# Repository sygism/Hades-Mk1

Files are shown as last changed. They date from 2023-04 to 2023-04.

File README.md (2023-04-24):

# Hades-Mk1

Hades-Mk1 is a collection of electronics designs for a quadcopter. This repository includes the designs for an NXP MCU based flight controller and compatible ESC (electronic speed controller) board for BLDC motors. More in-depth descriptions of the designs are included under the corresponding folders.

## Authors

  - **Markus Erik Sügis** - 
    [sygism](https://github.com/sygism)

## License

This project is not licensed and is free to be used in any way.

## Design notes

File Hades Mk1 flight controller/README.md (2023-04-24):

# Hades Mk1 FC board

The Hades Mk1 FCU board is designed for quadcopter control.

## Microcontroller unit

## Authors

  - **Markus Erik Sügis** - 
    [sygism](https://github.com/sygism)

## License

This project is not licensed and is free to be used in any way.

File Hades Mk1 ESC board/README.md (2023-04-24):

# Hades Mk1 ESC board

The Hades Mk1 ESC board is designed for 20-30A BLDC motor speed control. The board receives commands from the FCU (flight controller unit) through a PWM signal.
The board is powered by a 3C LiPo battery and is capable of 5VDC output. For rotor position sensing, the EMF method is used.

## Microcontroller unit

The brains behind the brawn is a Texas Instruments design, more specifically [TMS320F28027PTS](https://www.ti.com/product/TMS320F28027/part-details/TMS320F28027PTS), made specifically realtime signal processing.
The unit has 32-bit architecture.

## Motor driving logic

The board is capable of driving a 3P motor, hence it requires 6 transistors, setup as switches. By driving different transistor combinations
different phases of the motor can be powered. The transistors are driven by a MOSFET driver IC.

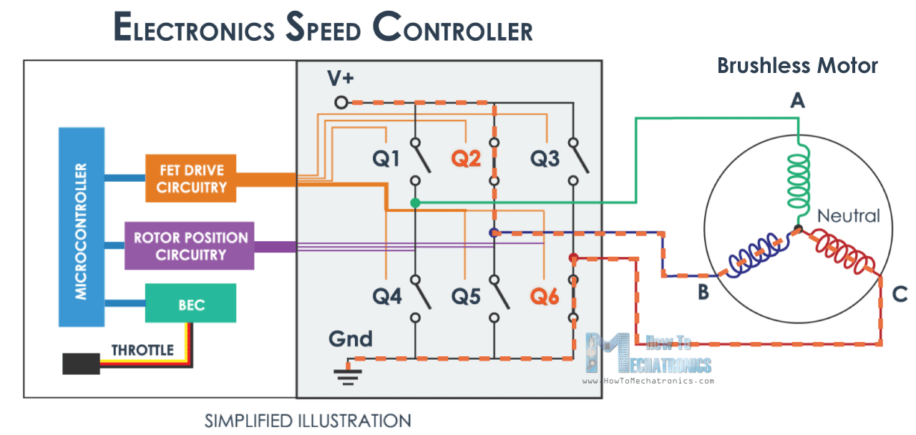
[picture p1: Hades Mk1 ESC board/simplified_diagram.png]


A simplified diagram of how this ESC board works.

Drawing credits to [HowToMechatronics](https://howtomechatronics.com/wp-content/uploads/2019/02/How-does-an-ESC-Work-Electronic-Speed-Controller.png).

## Authors

  - **Markus Erik Sügis** - 
    [sygism](https://github.com/sygism)

## License

This project is not licensed and is free to be used in any way.

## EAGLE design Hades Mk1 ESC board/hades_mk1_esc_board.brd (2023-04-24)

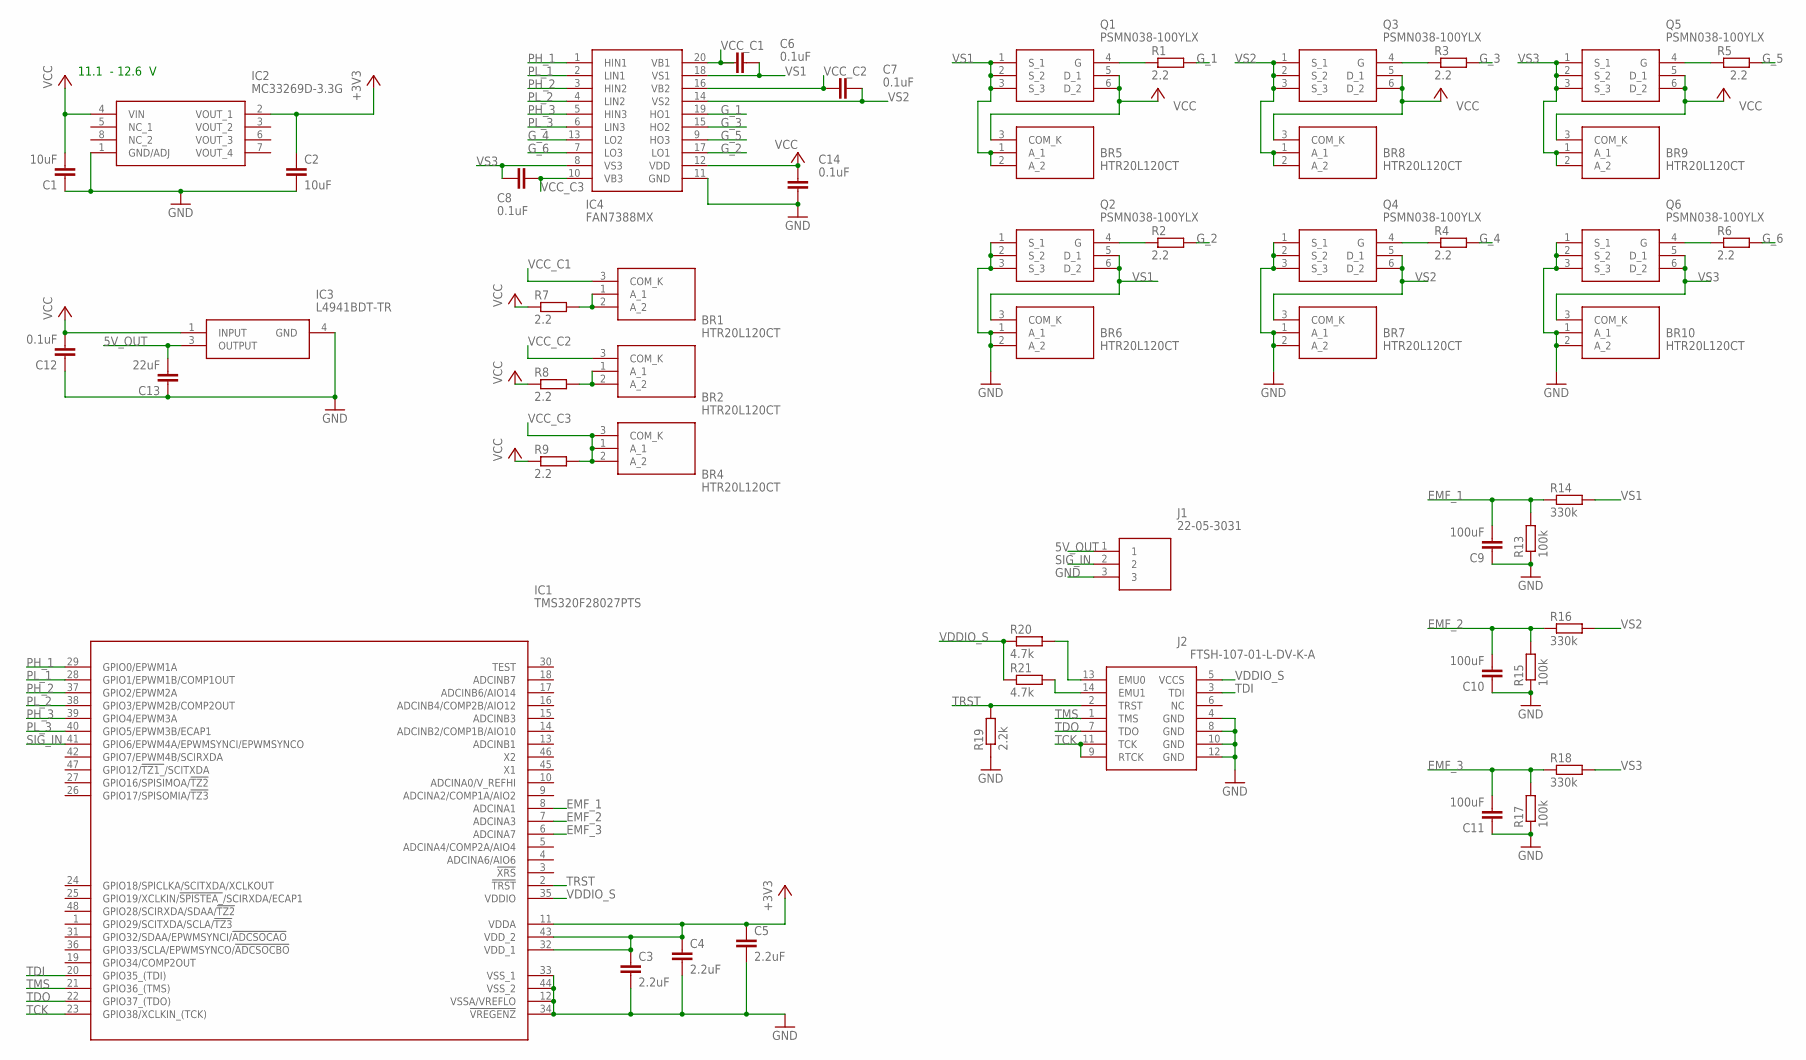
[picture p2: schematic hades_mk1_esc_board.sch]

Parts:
BR1, BR2, BR4, BR5, BR6, BR7, BR8, BR9, BR10: HTR20L120CT
C1, C2: 10uF; C0603
C3, C4, C5: 2.2uF; C0603
C6, C7, C8, C12, C14: 0.1uF; C0603
C9, C10, C11: 100uF; C0603
C13: 22uF; C0603
IC1: TMS320F28027PTS; QFP50P900X900X160-48N
IC2: MC33269D-3.3G; SOIC127P600X175-8N
IC3: L4941BDT-TR; TO228P972X240-3N
IC4: FAN7388MX; SOIC127P1032X265-20N
J1: 22-05-3031; SHDRRA3W87P0X254_1X3_747X818X6
J2: FTSH-107-01-L-DV-K-A; FTSH-107-XX-YYY-DV-K-A
Q1, Q2, Q3, Q4, Q5, Q6: PSMN038-100YLX; PSMN028100YS115
R1, R2, R3, R4, R5, R6, R7, R8, R9: 2.2; R0603
R13, R15, R17: 100k; R0603
R14, R16, R18: 330k; R0603
R19: 2.2k; R0603
R20, R21: 4.7k; R0603

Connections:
5V_OUT: C13.2, IC3.3 (OUTPUT), J1.1
+3V3: C2.1, C3.1, C4.1, C5.1, IC1.11 (VDDA), IC1.32 (VDD_1), IC1.43 (VDD_2), IC2.2 (VOUT_1)
EMF_1: C9.2, IC1.8 (ADCINA1), R13.2, R14.1
EMF_2: C10.2, IC1.7 (ADCINA3), R15.2, R16.1
EMF_3: C11.2, IC1.6 (ADCINA7), R17.2, R18.1
GND: BR6.1 (A_1), BR6.2 (A_2), BR7.1 (A_1), BR7.2 (A_2), BR10.1 (A_1), BR10.2 (A_2), C1.1, C2.2, C3.2, C4.2, C5.2, C9.1, C10.1, C11.1, C12.1, C13.1, C14.2, IC1.12 (VSSA/VREFLO), IC1.33 (VSS_1), IC1.34 (!VREGENZ), IC1.44 (VSS_2), IC2.1 (GND/ADJ), IC3.4 (GND), IC4.11 (GND), J1.3, J2.4 (GND), J2.8 (GND), J2.10 (GND), J2.12 (GND), Q2.1 (S_1), Q2.2 (S_2), Q2.3 (S_3), Q4.1 (S_1), Q4.2 (S_2), Q4.3 (S_3), Q6.1 (S_1), Q6.2 (S_2), Q6.3 (S_3), R13.1, R15.1, R17.1, R19.1
G_1: IC4.19 (HO1)
G_2: IC4.17 (LO1)
G_3: IC4.15 (HO2)
G_4: IC4.13 (LO2)
G_5: IC4.9 (HO3)
G_6: IC4.7 (LO3)
unnamed: J2.14 (EMU1), R21.2
unnamed: C1.2, IC2.4 (VIN)
unnamed: J2.13 (EMU0), R20.2
unnamed: Q1.4 (G), R1.1
unnamed: Q2.4 (G), R2.1
unnamed: Q3.4 (G), R3.1
unnamed: Q4.4 (G), R4.1
unnamed: Q5.4 (G), R5.1
unnamed: Q6.4 (G), R6.1
unnamed: BR2.1 (A_1), BR2.2 (A_2), R8.2
unnamed: BR4.1 (A_1), BR4.2 (A_2), BR4.3 (COM_K), R9.2
unnamed: BR1.1 (A_1), BR1.2 (A_2), R7.2
PH_1: IC1.29 (GPIO0/EPWM1A)
PH_2: IC1.37 (GPIO2/EPWM2A)
PH_3: IC1.39 (GPIO4/EPWM3A)
PL_1: IC1.28 (GPIO1/EPWM1B/COMP1OUT)
PL_2: IC1.38 (GPIO3/EPWM2B/COMP2OUT)
PL_3: IC1.40 (GPIO5/EPWM3B/ECAP1)
SIG_IN: IC1.41 (GPIO6/EPWM4A/EPWMSYNCI/EPWMSYNCO), J1.2
TCK: IC1.23 (GPIO38/XCLKIN_(TCK)), J2.9 (RTCK), J2.11 (TCK)
TDI: IC1.20 (GPIO35_(TDI)), J2.3 (TDI)
TDO: IC1.22 (GPIO37_(TDO)), J2.7 (TDO)
TMS: IC1.21 (GPIO36_(TMS)), J2.1 (TMS)
TRST: IC1.2 (!TRST), J2.2 (TRST), R19.2
VCC: BR5.3 (COM_K), BR8.3 (COM_K), BR9.3 (COM_K), C12.2, C14.1, IC3.1 (INPUT), IC4.12 (VDD), Q1.5 (D_1), Q1.6 (D_2), Q3.5 (D_1), Q3.6 (D_2), Q5.5 (D_1), Q5.6 (D_2), R7.1, R8.1, R9.1
VCC_C1: C6.2, IC4.20 (VB1)
VCC_C2: C7.1, IC4.16 (VB2)
VCC_C3: C8.2, IC4.10 (VB3)
VDDIO_S: IC1.35 (VDDIO), J2.5 (VCCS), R20.1, R21.1
VS1: BR5.1 (A_1), BR5.2 (A_2), BR6.3 (COM_K), C6.1, IC4.18 (VS1), Q1.1 (S_1), Q1.2 (S_2), Q1.3 (S_3), Q2.5 (D_1), Q2.6 (D_2), R14.2
VS2: BR7.3 (COM_K), BR8.1 (A_1), BR8.2 (A_2), C7.2, IC4.14 (VS2), Q3.1 (S_1), Q3.2 (S_2), Q3.3 (S_3), Q4.5 (D_1), Q4.6 (D_2), R16.2
VS3: BR9.1 (A_1), BR9.2 (A_2), BR10.3 (COM_K), C8.1, IC4.8 (VS3), Q5.1 (S_1), Q5.2 (S_2), Q5.3 (S_3), Q6.5 (D_1), Q6.6 (D_2), R18.2

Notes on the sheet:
11.1 - 12.6 V

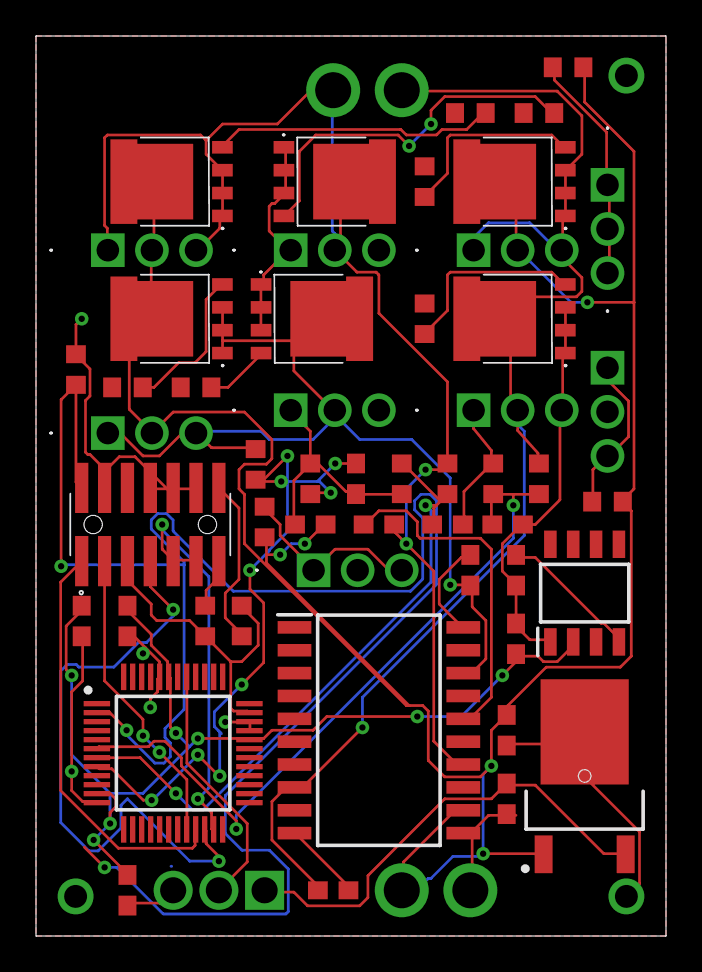
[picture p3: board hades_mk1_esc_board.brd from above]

Board: 2 copper layers, 35.0 x 50.0 mm, 53 parts (0 on the bottom side), 32 nets.
